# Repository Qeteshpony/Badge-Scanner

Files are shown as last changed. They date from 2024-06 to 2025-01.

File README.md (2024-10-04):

# NFC-Badge Scanner



3D Render
3D Render

[Hardware Documentation](https://qeteshpony.github.io/Badge-Scanner)

Raspberry Pi Pico W powered device to scan NFC-Badges and show a status on display

It is meant to be used with the widely available RFID-RC522 reader and the [DFROBOT LCD1602 RGB Backlight Module](https://raw.githubusercontent.com/DFRobot/DFRobot_RGBLCD/master/DFR0464%20Datasheet.pdf) but any other I2C Display should work as well. 

The device features an [I2C RTC](https://www.analog.com/media/en/technical-documentation/data-sheets/ds3231m.pdf) with backup battery connector and an SD-Card reader connected via SPI for data storage. 

There is also a buzzer that can be used for audible signals. 

Power can be provided through the USB port of the Pico or through a LiPo battery connected to the board. The LiPo battery can also be charged via the USB port and the device will switch seamlessly between battery and usb power.

The button can be used to send a shutdown signal to the microcontroller which then can power the whole device off by pulling a GPIO low. Pressing the button while the device is off or pluggin in USB will power it up again.

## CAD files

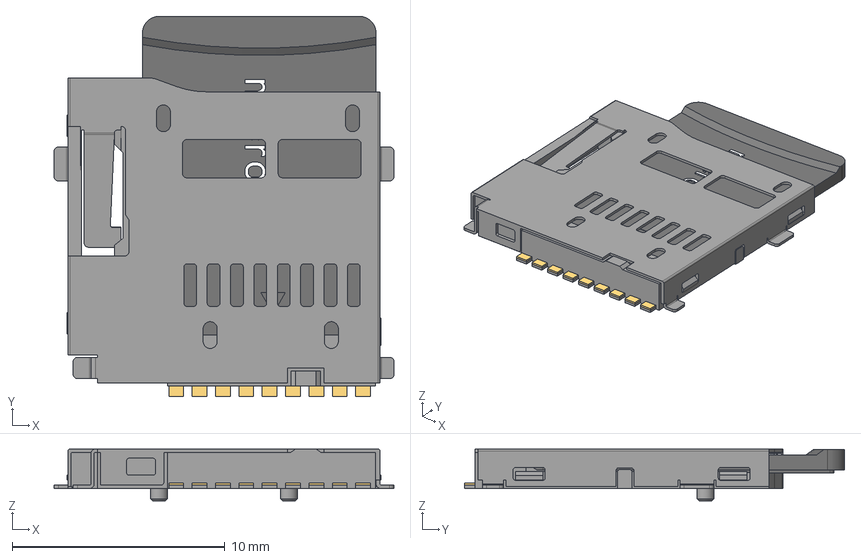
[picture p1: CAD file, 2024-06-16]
pcb/MicroSDSocket.step
16.0 x 17.9 x 2.44 mm
P1
sd
slot

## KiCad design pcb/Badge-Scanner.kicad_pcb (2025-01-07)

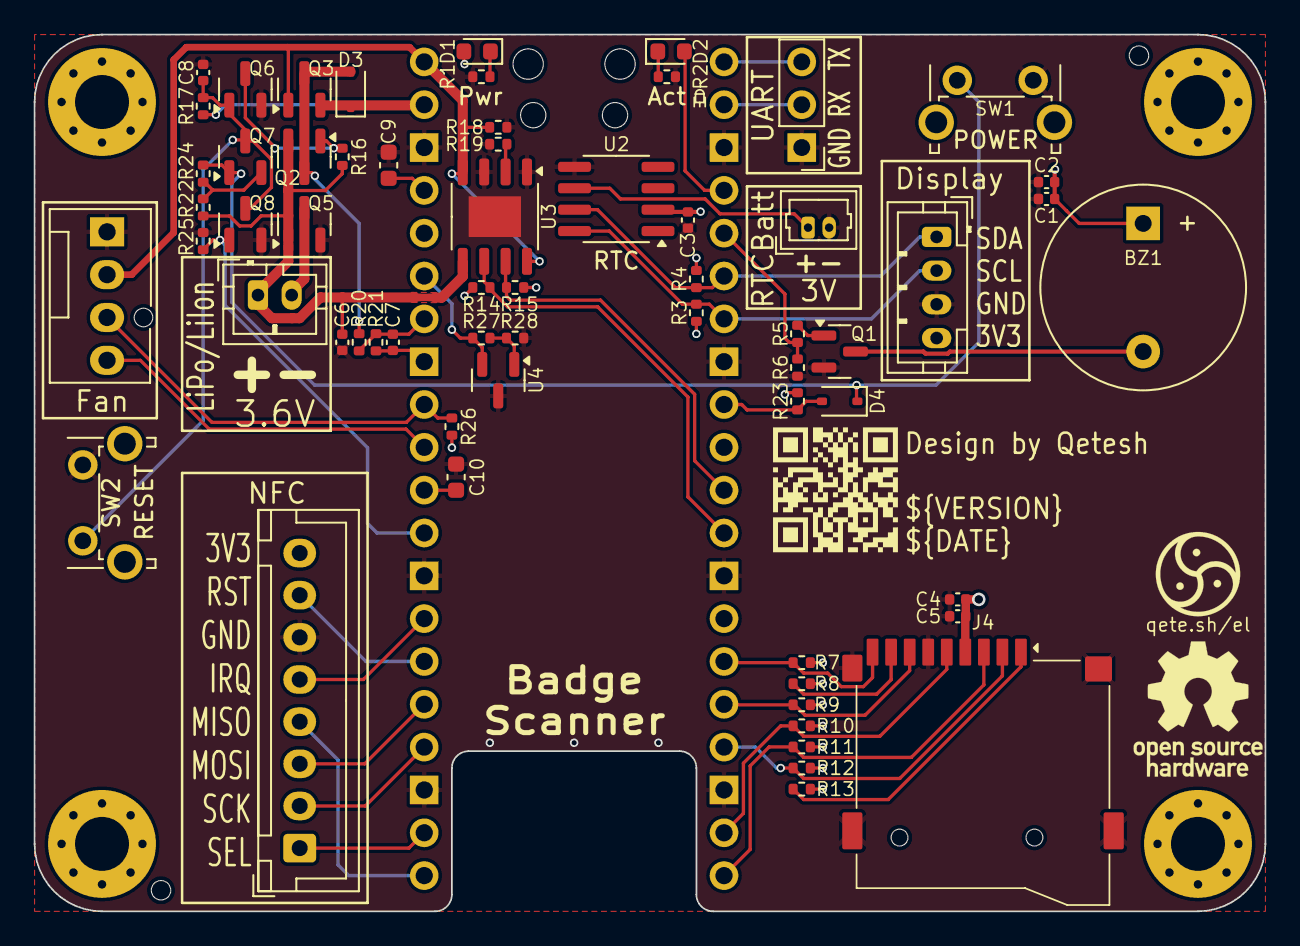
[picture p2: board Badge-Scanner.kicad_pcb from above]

Board: 2 copper layers, 73.0 x 52.0 mm, 63 parts (1 on the bottom side), 48 nets.

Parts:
BT1: Battery_Cell; Molex_PicoBlade_53047-0210_1x02_P1.25mm_Vertical
BT2: 18650; JST_PH_B2B-PH-K_1x02_P2.00mm_Vertical
BZ1: Buzzer; Buzzer_12x9.5RM7.6
C1, C3, C5, C7: 100n; C_0402_1005Metric
C2, C4, C6, C8: 10u; C_0402_1005Metric
C9, C10: 22u; C_0603_1608Metric
D1: Power; LED_0603_1608Metric
D2: Activity; LED_0603_1608Metric
D3, D4: 1N5819WS; D_SOD-323
J1: NFC-Module; JST_XH_B8B-XH-A_1x08_P2.50mm_Vertical
J2: Serial; PinHeader_1x03_P2.54mm_Vertical
J3: I2C; JST_PH_B4B-PH-K_1x04_P2.00mm_Vertical
J4: Micro_SD_Card_Det1; TF_PUSH_Micro-SD-Connector
M1: Fan; FanPinHeader_1x04_P2.54mm_Vertical
Q1, Q5, Q6, Q8: AO3400A; SOT-23
Q2, Q3, Q7: AO3401A; SOT-23
R1, R2: 680R; R_0402_1005Metric
R3, R4, R19, R27: 2k; R_0402_1005Metric
R5: 100R; R_0402_1005Metric
R6, R18, R20, R21, R23, R24: 100k; R_0402_1005Metric
R7, R8, R9, R10, R11, R12, R13: 3k3; R_0402_1005Metric
R14, R15, R25, R26, R28: 10k; R_0402_1005Metric
R16, R17: 1M; R_0402_1005Metric
R22: 1k; R_0402_1005Metric
SW1: Power; SW_Tactile_SPST_Angled_PTS645Vx58-2LFS
SW2: Reset; SW_Tactile_SPST_Angled_PTS645Vx31-2LFS
U1: Pico W; RPi_PicoW_SMD_TH_NoSilkscreenText
U2: DS3231MZ; SOIC-8_3.9x4.9mm_P1.27mm
U3: TP4056; HSOP-8-1EP_3.9x4.9mm_P1.27mm_EP2.41x3.1mm
U4: CJ431; SOT-23

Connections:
+3V3: BZ1.1 (+), C1.2, C2.2, C3.2, C4.2, C5.2, D1.2 (A), J1.8, J3.4, J4.4 (VDD), R3.2, R4.2, R7.1, R8.1, R9.1, R10.1, R11.1, R12.1, R13.1, R14.1, R15.1, R23.1, R26.1, U1.36 (3V3), U2.2 (VCC)
/3V3_EN: C9.2, U1.37 (3V3_EN)
/ADC_VREF: R27.1, U1.35 (ADC_VREF), U4.2 (K)
/BZ-: BZ1.2 (-), Q1.3 (D)
/BattPwrOff: Q8.1 (G), R25.2, U1.29 (GP22)
/BattVolt: C7.1, R20.2, R21.1, U1.34 (GP28)
/Battery Management/Batt+: BT2.1 (+), C6.1, Q2.2 (S), Q5.1 (G), R16.1, R22.1, U3.5 (BAT)
/Battery Management/Batt-: BT2.2 (-), Q5.3 (D)
/Battery Management/BattSw: C8.1, Q6.1 (G), Q7.3 (D), Q8.3 (D), R17.2, SW2.1
/Battery Management/BattSwG: Q2.1 (G), Q6.3 (D), R16.2
/Battery Management/BattSwd: D3.2 (A), Q2.3 (D), Q3.3 (D), R20.1
/Battery Management/PROG: R19.1, U3.2 (PROG)
/Battery Management/SW1: D4.1 (K), Q7.1 (G), R24.2, SW1.1
/Buzzer: R5.1, R6.1, U1.5 (GP3)
/FAN_PWM: M1.4 (PWM), U1.31 (GP26)
/FAN_TACHO: M1.3 (Tacho), R26.2, U1.32 (GP27)
/LED: D2.2 (A), U1.4 (GP2)
/NFC_CS: J1.1, U1.22 (GP17)
/NFC_IRQ: J1.5, U1.27 (GP21)
/NFC_MISO: J1.4, U1.21 (GP16)
/NFC_MOSI: J1.3, U1.25 (GP19)
/NFC_RST: J1.7, U1.26 (GP20)
/NFC_SCK: J1.2, U1.24 (GP18)
/RTC_VBAT: BT1.1 (+), U2.6 (VBAT)
/RUN: C10.2, U1.30 (RUN)
/SCL: J3.2, R3.1, U1.7 (GP5), U2.8 (SCL)
/SDA: J3.1, R4.1, U1.6 (GP4), U2.7 (SDA)
/SDCard/DAT1: J4.8 (DAT1), R8.2
/SDCard/DAT2: J4.1 (DAT2), R13.2
/SD_CS: J4.2 (DAT3/CD), R12.2, U1.17 (GP13)
/SD_DET: J4.9 (DET), R7.2, U1.15 (GP11)
/SD_MISO: J4.7 (DAT0), R9.2, U1.16 (GP12)
/SD_MOSI: J4.3 (CMD), R11.2, U1.20 (GP15)
/SD_SCK: J4.5 (CLK), R10.2, U1.19 (GP14)
/UART0RX: J2.2, U1.2 (GP1)
/UART0TX: J2.3, U1.1 (GP0)
/~Button: D4.2 (A), R23.2, U1.9 (GP6)
/~ChargeActive: R15.2, U1.11 (GP8), U3.7 (~CHRG)
/~ChargeStdby: R14.2, U1.12 (GP9), U3.6 (~STDBY)
GND: BT1.2 (-), C1.1, C2.1, C3.1, C4.1, C5.1, C6.2, C8.2, C9.1, C10.1, J1.6, J2.1, J3.3, J4.6 (VSS), J4.10 (SHIELD), M1.1 (-), Q1.2 (S), Q5.2 (S), Q6.2 (S), Q8.2 (S), R1.2, R2.2, R6.2, R18.2, R19.2, R25.1, R28.2, SW1.2, SW2.2, U1.3 (GND), U1.8 (GND), U1.13 (GND), U1.18 (GND), U1.23 (GND), U1.28 (GND), U1.38 (GND), U2.5 (GND), U3.1 (TEMP), U3.3 (GND), U3.9 (EP), U4.3 (A)
GNDA: C7.2, R21.2, U1.33 (AGND)
unnamed: D1.1 (K), R1.1
unnamed: D2.1 (K), R2.1
unnamed: Q1.1 (G), R5.2
unnamed: Q7.2 (S), R22.2, R24.1
unnamed: R27.2, R28.1, U4.1 (REF)
VBUS: M1.2 (+), Q3.1 (G), R18.1, U1.40 (VBUS), U3.4 (VCC), U3.8 (CE)
VSYS: D3.1 (K), Q3.2 (S), R17.1, U1.39 (VSYS)

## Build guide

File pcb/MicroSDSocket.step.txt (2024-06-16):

3D-Model by Omar Chavez Quispicusi 

Source: https://grabcad.com/library/micro-sd-card-socket-1

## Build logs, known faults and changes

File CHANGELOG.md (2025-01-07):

# Changelog

## [1.2.1](https://github.com/Qeteshpony/Badge-Scanner/compare/v1.2.0...v1.2.1) (2025-01-07)

### Bug Fixes

* re-release because of CI error ([4e137a9](https://github.com/Qeteshpony/Badge-Scanner/commit/4e137a9f02b33090910d54171756a40c091cc72e))

## [1.2.0](https://github.com/Qeteshpony/Badge-Scanner/compare/v1.1.0...v1.2.0) (2025-01-07)

### Features

* add reset button ([ce9ba01](https://github.com/Qeteshpony/Badge-Scanner/commit/ce9ba016b1cea4d7037d31c198c72740869c3f52))

### Bug Fixes

* add caps to delay startup of mcu ([efc946f](https://github.com/Qeteshpony/Badge-Scanner/commit/efc946f88fe66d377718ba1914e0ad7f4b4c1205))
* move measurement to BattSwd ([5e56296](https://github.com/Qeteshpony/Badge-Scanner/commit/5e562964bb7d4a31f9dfc941cf2e9115cc26b03e))
* move power LED to 3.3V rail ([da311a9](https://github.com/Qeteshpony/Badge-Scanner/commit/da311a986510c80a8789e43ebd1766c8498b42f8))
* turn around UART connector ([8cec761](https://github.com/Qeteshpony/Badge-Scanner/commit/8cec7613ee7b15c8cf737b2755fb1b465d007742))

## [1.1.0](https://github.com/Qeteshpony/Badge-Scanner/compare/v1.0.1...v1.1.0) (2024-10-10)

### Features

* add 3V reference for ADC ([cf62406](https://github.com/Qeteshpony/Badge-Scanner/commit/cf62406581093d005cda2081bfa9a6592ed4250c))
* add LiPo Circuitry ([dd25cb7](https://github.com/Qeteshpony/Badge-Scanner/commit/dd25cb7b9406531f7258caf2d13a5172d410a66b))
* optional fan connector ([cf62406](https://github.com/Qeteshpony/Badge-Scanner/commit/cf62406581093d005cda2081bfa9a6592ed4250c))
* place power button on the board ([8ff2f97](https://github.com/Qeteshpony/Badge-Scanner/commit/8ff2f97b8e190eabf7110a3696123f16641124c3))

### Bug Fixes

* add FET to measurement circuit ([584d771](https://github.com/Qeteshpony/Badge-Scanner/commit/584d7710a7379c05beeacbe2760a5b00a8ae9317))
* change resistor values for batt measurement ([623a018](https://github.com/Qeteshpony/Badge-Scanner/commit/623a018b7e6f91680762113eeb0c79d38aea8e0a))
* power switch circuit capacitance ([62879cc](https://github.com/Qeteshpony/Badge-Scanner/commit/62879cc400304d529d634c17997c11a03bb8ad99))
* remove wrong order number from SW1 ([87b65c3](https://github.com/Qeteshpony/Badge-Scanner/commit/87b65c3f2e208ec1de422eee4647292d34436d83))
* replace buzzer footprint ([c3924ff](https://github.com/Qeteshpony/Badge-Scanner/commit/c3924ffa6d855b0646060dfe17f83f52a8e4fc2d))

## [1.0.1](https://github.com/Qeteshpony/Badge-Scanner/compare/v1.0.0...v1.0.1) (2024-06-16)

### Bug Fixes

* part numbers for connectors ([e0aca50](https://github.com/Qeteshpony/Badge-Scanner/commit/e0aca50eb1ef129e9fa19aa4ba4945330c92ab33))

## 1.0.0 (2024-06-16)

### Features

* initial commit ([45014a9](https://github.com/Qeteshpony/Badge-Scanner/commit/45014a9e3f4de7e1946a6ffa00ebe2a186468ebe))

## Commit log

2024-06-16 feat: initial commit
    [Badge-Scanner.kicad_pcb, Badge-Scanner.kicad_sch, MicroSDSocket.step]
2024-06-16 style: add JLC order number position
    [Badge-Scanner.kicad_pcb]
2024-06-16 fix: part numbers for connectors
    [Badge-Scanner.kicad_pcb, Badge-Scanner.kicad_sch]
2024-09-26 feat: add LiPo Circuitry
    [Badge-Scanner.kicad_pcb, Badge-Scanner.kicad_sch, battery.kicad_sch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]
2024-09-26 style: silk screen cleanup
    [Badge-Scanner.kicad_pcb]
2024-09-27 fix: replace buzzer footprint
    [Badge-Scanner.kicad_pcb, Badge-Scanner.kicad_sch, battery.kicad_sch]
2024-09-27 feat: place power button on the board
    [Badge-Scanner.kicad_pcb, Badge-Scanner.kicad_sch, battery.kicad_sch]
2024-09-27 fix: add FET to measurement circuit
    Disable the battery measurement circuit when the device is switched off to save energy
    [Badge-Scanner.kicad_pcb, Badge-Scanner.kicad_sch, battery.kicad_sch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]
2024-10-02 fix: power switch circuit capacitance
    [Badge-Scanner.kicad_pcb, Badge-Scanner.kicad_sch, battery.kicad_sch]
2024-10-03 style: enlarge pin description text
    [Badge-Scanner.kicad_pcb]
2024-10-03 style: add some netclasses for schematic clarity
    [battery.kicad_sch]
2024-10-03 style: silkscreen improvements
    [Badge-Scanner.kicad_pcb]
2024-10-03 fix: remove wrong order number from SW1
    [Badge-Scanner.kicad_pcb, battery.kicad_sch]
2024-10-05 feat: optional fan connector
    feat: add 3V reference for ADC
    [Badge-Scanner.kicad_pcb, Badge-Scanner.kicad_sch]
2024-10-10 fix: change resistor values for batt measurement
    [Badge-Scanner.kicad_pcb, Badge-Scanner.kicad_sch, battery.kicad_sch]
2024-10-11 fix: turn around UART connector
    [Badge-Scanner.kicad_pcb, Badge-Scanner.kicad_sch]
2024-10-17 fix: move power LED to 3.3V rail
    VSYS is too unstable since its voltage changes a lot between usb and battery powered mode
    [Badge-Scanner.kicad_pcb, Badge-Scanner.kicad_sch]
2024-10-21 fix: move measurement to BattSwd
    [Badge-Scanner.kicad_pcb, battery.kicad_sch]
2024-10-21 fix: add caps to delay startup of mcu
    Sometimes the mcu does not boot correctly when usb gets connected while the system is off - most likely because the flash does not get enough power quick enough. Adding a startup delay for the 3V3 regulator and the mcu itself helps in my tests. This delays the boot by about half a second.
    [Badge-Scanner.kicad_pcb, Badge-Scanner.kicad_sch]
2025-01-07 feat: add reset button
    [Badge-Scanner.kicad_pcb, battery.kicad_sch]
2025-01-07 fix: re-release because of CI error
    [battery.kicad_sch]
